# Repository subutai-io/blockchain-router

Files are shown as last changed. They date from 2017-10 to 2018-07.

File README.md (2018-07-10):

# Subutai™ Blockchain Router

The Subutai™ Blockchain Router is a broadband cloud router and IoT gateway device designed to integrate with the blockchain. It is an open hardware project with sources available in this repository. Contents of the repository include:

* **FPGA** folder for IP cores and other FPGA Verilog projects
* **PCB** folder for the Subutai™ Blockchain Router's board designs

For more information about this project, please visit: https://subutai.io/router.html

Sunshine,
OptDyn Hardware Team

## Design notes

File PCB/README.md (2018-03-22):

# The PCB folder include Subutai™ Blockchain Router's design

The SRv2.0 folder include Subutai™ Blockchain Router's v2.0 design

For more information about this project, please visit: https://subutai.io/router.html

Sunshine,

OptDyn Hardware Team

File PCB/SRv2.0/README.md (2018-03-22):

# Subutai™ Blockchain Router
The Subutai™ Blockchain Router open hardware project sources.

The 3DRender includes the 3D pdf of the board.

Assembly folder includes the assembly drawing of the components on the board layout.

The BOM folder includes the BOM list of the PCB.

The DesignRuleCheck folder includes the Design Rule Check Results made.

The Manufacturing folder includes the Gerber, Drill, ODB++, Manufacturing pdf and Pick n Place documents.

The Project includes the schematic and Pcb files.

The SchematicPdf folder includes the schematic in the form of pdf.

For more information about this project, please visit: https://subutai.io/router.html

Sunshine,

OptDyn Hardware Team

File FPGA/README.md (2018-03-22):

# The FPGA folder includes IP cores, FPGA projects for Subutai™ Blockchain Router
The Subutai™ Blockchain Router open hardware project sources.

For more information about this project, please visit: https://subutai.io/router.html

Sunshine,

OptDyn Hardware Team

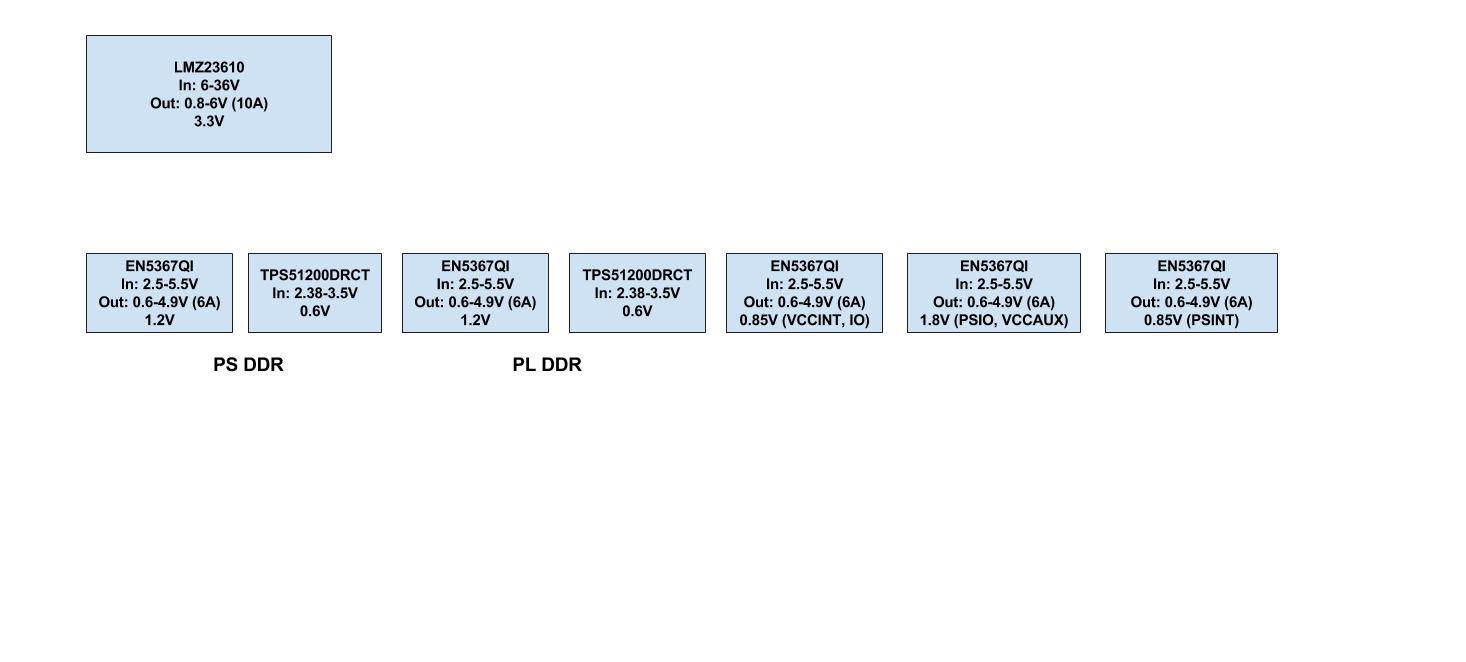
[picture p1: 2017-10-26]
PCB/SRv2.0/Documents/Power Regulators.jpg

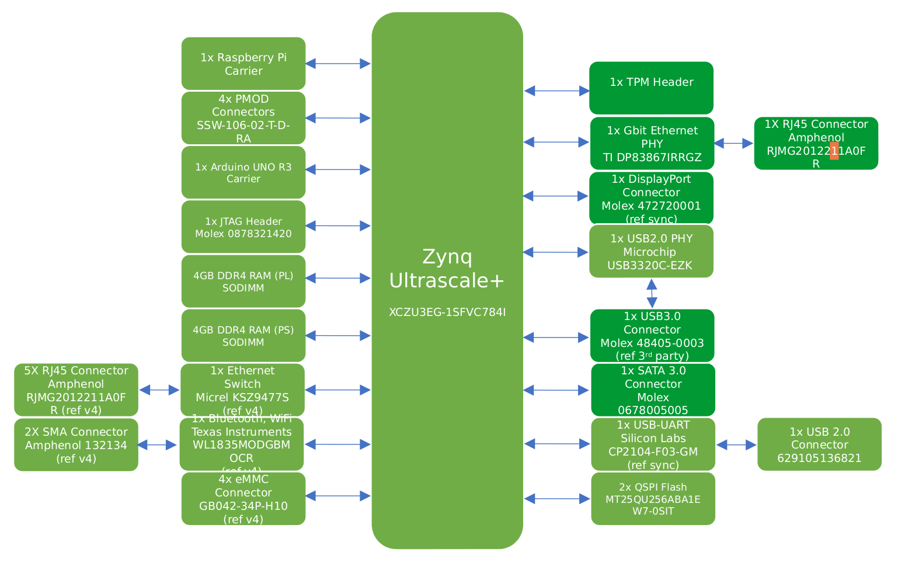
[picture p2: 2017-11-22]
PCB/SRv2.0/Documents/Screenshot from 2017-11-22 23-14-22.png

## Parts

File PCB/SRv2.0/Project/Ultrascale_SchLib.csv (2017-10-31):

LIBRARYREFERENCE | FOOTPRINT1 | .CHECKED PCB | .CHECKED SCH | .CREATOR | 3D PACKAGE | 3-STATE OUTPUT | ALLIED_NUMBER | ANTENNA TYPE | APPLICATIONS | AUTHOR | BITS(#) | C | CAPACITANCE | CAPACITANCE TOLERANCE | CAPACITANCE TOLERANCE ± | CAPACITOR TERMINALS | CARD TYPE | CASE | CATEGORY | CERAMIC CAPACITOR CASE | CHANNEL TYPE | CHANNELS PER CIRCUIT | CODE_IPC | CODE_JEDEC | COLOR | COMMENT | COMPONENT KIND | COMPONENT TYPE | COMPONENTHEIGHT | COMPONENTLINK1DESCRIPTION | COMPONENTLINK1URL | COMPONENTLINK2DESCRIPTION | COMPONENTLINK2URL | COMPONENTLINK3DESCRIPTION | COMPONENTLINK3URL | COMPOSITION | CONNECTOR STYLE | CONNECTOR TYPE | CONTACT FINISH | CONTACT FINISH - MATING | CONTACT FINISH - POST | CONTACT FINISH THICKNESS | CONTACT FINISH THICKNESS - MATING | CONTACT FINISH THICKNESS - POST | CONTACT LENGTH - MATING | CONTACT LENGTH - POST | CONTACT MATERIAL | CONTACT SHAPE | CONTACT TYPE | COPYRIGHT | CREATEDATE | CURRENT - OUTPUT | CURRENT - OUTPUT HIGH, LOW | CURRENT - PEAK PULSE (10/1000µS) | CURRENT - QUIESCENT (MAX) | CURRENT - RECEIVING | CURRENT - SATURATION | CURRENT - SUPPLY (DISABLE) (MAX) | CURRENT - SUPPLY (MAX)
0878321420 | 0878321420 |  |  |  |  |  |  |  |  |  |  |  |  |  |  |  |  |  |  |  |  |  |  |  |  | 0878321420 |  |  |  | Drawing | C:\Users\Public\Documents\Altium\AD16\Library\PDF\878322620_sd.pdf
2309409-2 | DDR4_SODIMM_MATING |  |  |  |  |  |  |  |  |  |  |  |  |  |  |  |  |  |  |  |  |  |  |  |  | 2309409-2 |  |  |  | Datasheet | C:\Users\Public\Documents\Altium\AD16\Library\PDF\ENG_CD_2309409_3.pdf
ABM8G-25.000MHZ-18-D2Y-T | ABM8G |  |  |  |  |  |  |  |  |  |  |  |  |  |  |  |  |  |  |  |  |  |  |  |  | ABM8G-25.000MHZ-18-D2Y-T |  |  |  | Datasheet | C:\Users\Public\Documents\Altium\AD16\Library\PDF\ABM8G.pdf
ABS07AIG-32.768KHZ-1-T | ABS07 |  |  |  |  |  |  |  |  |  |  |  |  |  |  |  |  |  |  |  |  |  |  |  |  | ABS07AIG-32.768KHZ-1-T |  |  |  | Datasheet | C:\Users\Public\Documents\Altium\AD16\Library\PDF\ABS07.pdf
ADP223ACPZ-R7 | CP-8-10_LFCSP_UD |  |  |  |  |  |  |  |  |  |  |  |  |  |  |  |  |  |  |  |  |  |  |  |  | ADP223ACPZ-R7 |  |  |  | Datasheet | C:\Users\Public\Documents\Altium\AD16\Library\PDF\ADP222_223_224_225.pdf |  |  |  |  |  |  |  |  |  |  |  |  |  |  |  |  |  |  |  |  | 300mA
ASDMB-24.000MHZ-LY-T | ASDMB |  |  |  |  |  |  |  |  |  |  |  |  |  |  |  |  |  |  |  |  |  |  |  |  | ASDMB-24.000MHZ-LY-T |  |  |  | Datasheet | C:\Users\Public\Documents\Altium\AD16\Library\PDF\ASDMB.pdf
ASDMB-33.333MHZ-LY-T | ASDMB |  |  |  |  |  |  |  |  |  |  |  |  |  |  |  |  |  |  |  |  |  |  |  |  | ASDMB-33.333MHZ-LY-T |  |  |  | Datasheet | C:\Users\Public\Documents\Altium\AD16\Library\PDF\ASDMB.pdf
AT34C02D-MAHM | UDFN_9 |  |  |  |  |  |  |  |  |  |  |  |  |  |  |  |  |  |  |  |  |  | SOIC127P600-8 | MS-012-AA |  | AT34C02D-MAHM |  |  |  | Datasheet | C:\Users\Public\Documents\Altium\AD16\Library\PDF\Atmel-8781-SEEPROM-AT34C02D-Datasheet.pdf
BEAD0603_220_2A5_40M | INDC1608N_0603 |  |  |  |  |  |  |  |  |  |  |  |  |  |  |  |  |  |  |  |  |  |  |  |  |  |  |  |  | Datasheet | C:\Users\Public\Documents\Altium\AD16\Library\PDF\ENFA0003.pdf
BSS138-7-F | DIODES_SOT23 |  |  |  |  |  |  |  |  |  |  |  |  |  |  |  |  |  |  |  |  |  |  |  |  | BSS138-7-F |  |  |  | Datasheet | C:\Users\Public\Documents\Altium\AD16\Library\PDF\ds30144.pdf
C0603X5R1E104K030BB | CAP_0603 |  |  |  |  |  |  |  | General Purpose |  |  |  |  |  |  |  |  |  |  |  |  |  |  |  |  | *
C0805C105K5RACTU | C0805C105 |  |  |  | * |  | * |  | General Purpose |  |  |  |  |  |  |  |  |  |  |  |  |  |  |  |  | *
C0805C106K4PACTU | CAP 0805 |  |  |  | * |  | * |  | General Purpose |  |  |  |  |  |  |  |  |  |  |  |  |  |  |  |  | *
C3216X5R | CAPC3216X180N |  |  |  | * |  | * |  |  |  |  |  |  |  |  |  |  |  |  |  |  |  |  |  |  | C3216X5R1C476M160AB
CAP 04023C103KAT2A | CAPC1005X56N |  |  |  |  |  |  |  |  |  |  |  | 10000pF |  |  |  |  |  |  |  |  |  |  |  |  | 04023C103KAT2A
CAP 04023C104 | CAP 04023C104 |  |  |  | * |  | * |  |  |  |  |  |  |  |  |  |  |  |  |  |  |  |  |  |  | 04023C104KAT2A
CAP 0402ZD106 | CAP 0402ZD106 |  |  |  |  |  |  |  |  |  |  |  |  |  |  |  |  |  |  |  |  |  |  |  |  | 0402ZD106MAT2A
CAP 06035C104 | CAP 06035C104 |  |  |  |  |  | 70002065 |  |  |  |  |  |  |  |  |  |  |  |  |  |  |  |  |  |  | 06035C104KAT2A
CAP 08053D475KAT2A | CAPC2012X140N |  |  |  |  |  |  |  |  |  |  |  | 4.7µF |  |  |  |  |  |  |  |  |  |  |  |  | 08053D475KAT2A
CAP C1005X5R1A475K050BC | CAPC1005X5 |  |  |  |  |  |  |  |  |  |  |  | 4.7µF |  |  |  |  |  |  |  |  |  |  |  |  | C1005X5R1A475K050BC
CAP C1608X5R1A226M080AC | CAPC1608X80N |  |  |  |  |  |  |  |  |  |  |  | 22µF |  |  |  |  |  |  |  |  |  |  |  |  | C1608X5R1A226M080AC
CAP C2012X5R1E226M125AC | CAPC2012X145N |  |  |  |  |  |  |  |  |  |  |  | 22µF |  |  |  |  |  |  |  |  |  |  |  |  | C2012X5R1E226M125AC
CAP C3216X5R1C476M160AB | CAPC3216X180N |  |  |  |  |  |  |  |  |  |  |  | 47µF |  |  |  |  |  |  |  |  |  |  |  |  | C3216X5R1C476M160AB
CAP GRM155R61E105KA12D | CAPC1005X55N |  |  |  |  |  |  |  |  |  |  |  | 1µF |  |  |  |  |  |  |  |  |  |  |  |  | GRM155R61E105KA12D
CAP GRM188R61E225KA12D | CAPC1608X90N |  |  |  |  |  |  |  |  |  |  |  | 2.2µF |  |  |  |  |  |  |  |  |  |  |  |  | GRM188R61E225KA12D
CAP GRM31CR61E226 | CAP GRM31CR61E226 |  |  |  |  |  |  |  | General Purpose |  |  |  |  |  |  |  |  |  |  |  |  |  |  |  |  | GRM31CR61E226KE15L
CAPCER0402 | CAPC1005L_0402 |  |  |  |  |  |  |  |  |  |  |  |  |  |  |  |  |  |  |  |  |  |  |  |  | =Value |  |  |  | Datasheet
CAPCER0402C0G27P50V_5T | CAPC1005L_0402 |  |  |  |  |  |  |  |  |  |  |  |  |  |  |  |  |  |  |  |  |  |  |  |  | =Value |  |  |  | Datasheet
CAPCER0402C0G68P50V_5T | CAPC1005L_0402 |  |  |  |  |  |  |  |  |  |  |  |  |  |  |  |  |  |  |  |  |  |  |  |  | =Value |  |  |  | Datasheet
CAPCER0402X5R0U4710V_10T | CAPC1005L_0402 |  |  |  |  |  |  |  |  |  |  |  |  |  |  |  |  |  |  |  |  |  |  |  |  | =Value |  |  |  | Datasheet
CAPCER0402X5R10U10V_20T | CAPC1005L_0402 |  |  |  |  |  |  |  |  |  |  |  |  |  |  |  |  |  |  |  |  |  |  |  |  | =Value |  |  |  | Datasheet
CAPCER0402X5R1U16V_20T | CAPC1005L_0402 |  |  |  |  |  |  |  |  |  |  |  |  |  |  |  |  |  |  |  |  |  |  |  |  | =Value |  |  |  | Datasheet
CAPCER0402X5R2U210V_10T | CAPC1005L_0402 |  |  |  |  |  |  |  |  |  |  |  |  |  |  |  |  |  |  |  |  |  |  |  |  | =Value |  |  |  | Datasheet
CAPCER0402X5R4U710V_10T | CAPC1005L_0402 |  |  |  |  |  |  |  |  |  |  |  |  |  |  |  |  |  |  |  |  |  |  |  |  | =Value |  |  |  | Datasheet
CAPCER0402X7R1000P50V_10T | CAPC1005L_0402 |  |  |  |  |  |  |  |  |  |  |  |  |  |  |  |  |  |  |  |  |  |  |  |  | =Value |  |  |  | Datasheet
CAPCER0402X7R100N25V_10T | CAPC1005L_0402 |  |  |  |  |  |  |  |  |  |  |  |  |  |  |  |  |  |  |  |  |  |  |  |  | =Value |  |  |  | Datasheet
CAPCER0402X7R10N50V_10T | CAPC1005L_0402 |  |  |  |  |  |  |  |  |  |  |  |  |  |  |  |  |  |  |  |  |  |  |  |  | =Value |  |  |  | Datasheet
CAPCER0402X7R22N50V_10T | CAPC1005L_0402 |  |  |  |  |  |  |  |  |  |  |  |  |  |  |  |  |  |  |  |  |  |  |  |  | =Value |  |  |  | Datasheet
CAPCER0402X7R2700P50V_10T | CAPC1005L_0402 |  |  |  |  |  |  |  |  |  |  |  |  |  |  |  |  |  |  |  |  |  |  |  |  | =Value |  |  |  | Datasheet
CAPCER0603X5R22U10V_20T | CAPC1608L_0603 |  |  |  |  |  |  |  |  |  |  |  |  |  |  |  |  |  |  |  |  |  |  |  |  | =Value |  |  |  | Datasheet
CAPCER0805X5R22U25V_20T | CAPC2012L_0805 |  |  |  |  |  |  |  |  |  |  |  |  |  |  |  |  |  |  |  |  |  |  |  |  | =Value |  |  |  | Datasheet
CAPCER1206X5R47U25V_20T | CAPC3216L_1206 |  |  |  |  |  |  |  |  |  |  |  |  |  |  |  |  |  |  |  |  |  |  |  |  | =Value |  |  |  | Datasheet
CAPCER1210X5R100U16V_20T | CAPC3225N_1210 |  |  |  |  |  |  |  |  |  |  |  |  |  |  |  |  |  |  |  |  |  |  |  |  | =Value |  |  |  | Datasheet
CAPCER1210X5R220U6V3_20T | CAPC3225N_1210 |  |  |  |  |  |  |  |  |  |  |  |  |  |  |  |  |  |  |  |  |  |  |  |  | =Value |  |  |  | Datasheet
CAPELE0603TAN47U6V3_20T | AVX_TAN_F38_M_0603 |  |  |  |  |  |  |  |  |  |  |  |  |  |  |  |  |  |  |  |  |  |  |  |  | =Value |  |  |  | Datasheet | C:\Users\Public\Documents\Altium\AD16\Library\PDF\f38.pdf
CAPELE0905TAN100U6V3_20T | AVX_TAN_F95_P_0905 |  |  |  |  |  |  |  |  |  |  |  |  |  |  |  |  |  |  |  |  |  |  |  |  | =Value |  |  |  | Datasheet | C:\Users\Public\Documents\Altium\AD16\Library\PDF\F95.pdf
CON RJ-45 RJMG2012211A0FR | CON_MODULAR_RJ45_TH_RA_RJMG2012211A0FR |  |  |  |  |  |  |  |  |  |  |  |  |  |  |  |  |  |  |  |  |  |  |  |  | =Value |  |  |  | Datasheet | https://www.amphenolcanada.com/ProductSearch/Drawings/AC/RJMG2012211A0FR.PDF
CONN 39-30-1060 | 39-30-1060 |  |  |  |  |  |  |  |  |  |  |  |  |  |  |  |  |  |  |  |  |  |  |  |  | 39-30-1060 |  |  |  |  |  |  |  |  |  |  |  | Header |  | Tin | Tin |  | 100µin (2.54µm) | 100µin (2.54µm) |  | 0.142 (3.60mm)" | Brass | Square | Male Pin
CONN 878321420 | 87832-1420 |  |  |  |  |  |  |  |  |  |  |  |  |  |  |  |  |  |  |  |  |  |  |  |  | CONN 878321420 |  |  |  |  |  |  |  |  |  |  |  | Header |  | Gold | Tin |  | 74.8µin (1.90µm) |  | 0.141 (3.60mm)" |  | Phosphor Bronze | Square | Male Pin
CP2104-F03-GM | SLAB-QFN-24-2675x2675TP_L |  |  |  |  |  |  |  |  |  |  |  |  |  |  |  |  |  |  |  |  |  | J-STD-020 | MO-220 |  | CP2104-F03-GM |  |  |  | Manufacturer URL | http://www.silabs.com/ | Datasheet | C:\Users\Public\Documents\Altium\AD16\Library\PDF\cp2104.pdf | Package Specification | http://www.silabs.com/Support%20Documents/TechnicalDocs/C8051F93x-92x.pdf
CRCW020111K0FKED | RES_V0201 |  |  |  |  |  |  |  |  |  |  | Copyright (C) 2015 Accelerated Designs. All rights reserved |  |  |  |  |  |  |  |  |  |  |  |  |  | * |  |  |  |  |  |  |  |  |  |  |  |  |  |  |  |  |  |  |  |  |  |  |  | Copyright (C) 2015 Accelerated Designs. All rights reserved
CRCW0201240RFNED | RESC0603X28N |  |  |  | * |  | * |  |  |  |  |  |  |  |  |  |  |  |  |  |  |  |  |  |  | CRCW0201240RFNED
CRCW02012K49FKED | RC0201N |  |  |  |  |  |  |  |  |  |  | Copyright (C) 2015 Accelerated Designs. All rights reserved |  |  |  |  |  | 0201 (0603 metric) |  |  |  |  |  |  |  | * |  |  |  |  |  |  |  |  |  | Thick Film |  |  |  |  |  |  |  |  |  |  |  |  |  | Copyright (C) 2015 Accelerated Designs. All rights reserved
Capacitor - non polarized | CAPC1608X87N |  |  |  |  |  |  |  |  | CERN DEM JLC |  |  | 0.1 | ± 10% | ± 10% | SMD |  | 0603 |  | 0603 [1608 Metric] |  |  |  |  |  | =Value | Standard | Standard |  |  |  |  |  |  |  |  |  |  |  |  |  |  |  |  |  |  |  |  |  |  | 3.12.2007
Capacitor NP | CAP_C_0402 |  |  |  |  |  |  |  |  |  |  |  |  |  |  |  |  |  | Capacitor |  |  |  |  |  |  | Capacitor NP |  |  |  | Datasheets | https://chn-vm-apps.microchip.com/mchprepo/parts/Datasheets/TDKMLCCCapRange.pdf
Coax_1Female_1Shield | HUBER-SUHNER_82 SMA-50-0-41/133 NE |  |  |  |  |  |  |  |  | CERN DEM JLC |  |  |  |  |  |  |  |  |  |  |  |  |  |  |  | Coax_1Female_1Shield | Standard | Standard | 9.6mm |  |  |  |  |  |  |  |  |  |  |  |  |  |  |  |  |  |  |  |  |  | 20.04.2010
D CDSOT23-SR208 | SOT95P280X130-6N |  |  |  |  |  |  |  |  |  |  |  |  |  |  |  |  |  |  |  |  |  |  |  |  | CDSOT23-SR208
D MBRS240LT3G | DIOM5436X247N |  |  |  | * |  | 70099506 |  |  |  |  |  |  |  |  |  |  |  |  |  |  |  |  |  |  | MBRS240LT3G
D TPD2EUSB30DRTR | SOTFL35P100X50-3N |  |  |  |  |  |  |  |  |  |  |  |  |  |  |  |  |  |  |  |  |  |  |  |  | TPD2EUSB30DRTR |  |  |  |  |  |  |  |  |  |  |  |  |  |  |  |  |  |  |  |  |  |  |  |  |  |  |  | 1A (8/20µs)
D TPD4E001DRLR | SOTFL50P160X60-6N |  |  |  |  |  |  |  | Ethernet |  |  |  |  |  |  |  |  |  |  |  |  |  |  |  |  | TPD4E001DRLR
DP83867IRRGZ | QFN50P700X700X100_HS-49N |  |  |  |  |  |  |  |  |  |  |  |  |  |  |  |  |  |  |  |  |  |  |  |  | DP83867IRRGZ |  |  |  | Datasheet | C:\Users\Public\Documents\Altium\AD16\Library\PDF\dp83867ir.pdf
DSC1101B12-125.0000 | OSC_5MX3M2_A |  |  |  |  |  |  |  |  |  |  |  |  |  |  |  |  |  | Crystals and Oscillators |  |  |  |  |  |  | =value |  |  |  | Datasheet | http://www.ctscorp.com/components/Datasheets/008-0256-0.pdf
DisplayPort | 8470-2-2-X |  |  |  |  |  |  |  |  |  |  |  |  |  |  |  |  |  |  |  |  |  |  |  |  | * |  |  |  |  |  |  |  |  |  |  |  | DisplayPort | Gold
ERJ-1GEF2211C | RC0201N |  |  |  |  |  |  |  |  |  |  | Copyright (C) 2015 Accelerated Designs. All rights reserved |  |  |  |  |  | 0201 (0603 metric) |  |  |  |  |  |  |  | * |  |  |  |  |  |  |  |  |  | Thick Film |  |  |  |  |  |  |  |  |  |  |  |  |  | Copyright (C) 2015 Accelerated Designs. All rights reserved
ERJ-1GEF5761C | RC0201N |  |  |  |  |  |  |  |  |  |  | Copyright (C) 2015 Accelerated Designs. All rights reserved |  |  |  |  |  | 0201 (0603 metric) |  |  |  |  |  |  |  | * |  |  |  |  |  |  |  |  |  | Thick Film |  |  |  |  |  |  |  |  |  |  |  |  |  | Copyright (C) 2015 Accelerated Designs. All rights reserved
ERJ-1GEF8061C | RC0201N |  |  |  |  |  |  |  |  |  |  | Copyright (C) 2015 Accelerated Designs. All rights reserved |  |  |  |  |  | 0201 (0603 metric) |  |  |  |  |  |  |  | * |  |  |  |  |  |  |  |  |  | Thick Film |  |  |  |  |  |  |  |  |  |  |  |  |  | Copyright (C) 2015 Accelerated Designs. All rights reserved
F BLM15AG601SN1D | BEADC1005X55N |  |  |  |  |  |  |  |  |  |  |  |  |  |  |  |  |  |  |  |  |  |  |  |  | BLM15AG601SN1D
FIN1019MTCX | TSOP65P640X120-14N |  |  |  |  |  |  |  |  |  |  |  |  |  |  |  |  |  |  |  |  |  |  |  |  | *
Ferrite Bead | IND_C_0805 |  |  |  |  |  |  |  |  |  |  |  |  |  |  |  |  |  | Inductor |  |  |  |  |  |  | Ferrite Bead |  |  |  | Datasheet | https://chn-vm-apps.microchip.com/mchprepo/parts/Datasheets/beads_commercial_power_mpz_en
GB042-34P-H10 | GB042-34P-H10 |  |  |  |  |  |  |  |  |  |  |  |  |  |  |  |  |  |  |  |  |  |  |  |  | GB042-34P-H10
GRM033R61A225KE47D | CAPC0603X33N |  |  |  |  |  |  |  |  |  |  |  |  |  |  |  |  |  |  |  |  |  |  |  |  | GRM033R61A225KE47D
Header 1x2 | HDR_M_2.54_1x2 |  |  |  |  |  |  |  |  |  |  |  |  |  |  |  |  |  |  |  |  |  |  |  |  | =value
IND3030_2U2_1A8_72M | IND_SRN3015 |  |  |  |  |  |  |  |  |  |  |  |  |  |  |  |  |  |  |  |  |  |  |  |  |  |  |  |  | Datasheet | C:\Users\Public\Documents\Altium\AD16\Library\PDF\SRN3015.pdf |  |  |  |  |  |  |  |  |  |  |  |  |  |  |  |  |  |  |  |  |  |  |  |  |  | 1.65A
IND5752_3U3_5A_38M | IND_SRP5030T |  |  |  |  |  |  |  |  |  |  |  |  |  |  |  |  |  |  |  |  |  |  |  |  |  |  |  |  | Datasheet | C:\Users\Public\Documents\Altium\AD16\Library\PDF\SRP5030T.pdf |  |  |  |  |  |  |  |  |  |  |  |  |  |  |  |  |  |  |  |  |  |  |  |  |  | 8A
INDC2520_1U5_2A9_66M | INDC2520 |  |  |  |  |  |  |  |  |  |  |  |  |  |  |  |  |  |  |  |  |  |  |  |  |  |  |  |  | Datasheet | C:\Users\Public\Documents\Altium\AD16\Library\PDF\ihhp-1008ab-01.pdf |  |  |  |  |  |  |  |  |  |  |  |  |  |  |  |  |  |  |  |  |  |  |  |  |  | 3.4A
IRPS5401MTRPBF | QFN40P700X700X90_HS-57N |  |  |  |  |  |  |  |  |  |  |  |  |  |  |  |  |  |  |  |  |  |  |  |  | IRPS5401MTRPBF |  |  |  | Datasheet | C:\Users\Public\Documents\Altium\AD16\Library\PDF\Infineon-PB-IRPS5401-PB-v01_00-EN.pdf
Inductor | IND_TAI_NR_L3W3H1.5 |  |  |  |  |  |  |  |  |  |  |  |  |  |  |  |  |  | Inductor |  |  |  |  |  |  | Inductor |  |  |  | Datasheet | https://chn-vm-apps.microchip.com/mchprepo/parts/Datasheets/NR3015T1R0N.pdf
KSZ9477S_TQFP128 | TQFP-128_14x14_EP10x10 |  |  |  |  |  |  |  |  |  |  |  |  |  |  |  |  |  |  |  |  |  |  |  |  | =Value
LED0603BLUE | LED0603BLUE |  |  |  |  |  |  |  |  |  |  |  |  |  |  |  |  |  |  |  |  |  |  |  |  |  |  |  |  | Datasheet | C:\Users\Public\Documents\Altium\AD16\Library\PDF\AV02-0592EN0.pdf
LED0603GREEN | LED0603GREEN |  |  |  |  |  |  |  |  |  |  |  |  |  |  |  |  |  |  |  |  |  |  |  |  |  |  |  |  | Datasheet | C:\Users\Public\Documents\Altium\AD16\Library\PDF\AV02-0592EN0.pdf
LED0603RED | LED0603RED |  |  |  |  |  |  |  |  |  |  |  |  |  |  |  |  |  |  |  |  |  |  |  |  |  |  |  |  | Datasheet | C:\Users\Public\Documents\Altium\AD16\Library\PDF\AV02-0592EN0.pdf
M20-7820646 | Hdr_Female_1x6_2.54mm | MM | MM | MM |  |  |  |  |  |  |  |  |  |  |  |  |  |  | Connectors, Interconnects |  |  |  |  |  | Black | HDR FMALE 1x6 2.54mm |  |  |  | http://harwin.com/includes/pdfs/M20-782.pdf | http://harwin.com/includes/pdfs/M20-782.pdf |  |  |  |  |  |  | Receptacle | Tin |  |  | - |  |  |  |  |  |  | Female Socket
M20-7820842 | Hdr_Female_1x8_2.54mm | RF | RF | MM |  |  |  |  |  |  |  |  |  |  |  |  |  |  | Connectors, Interconnects |  |  |  |  |  | Black | HDR FMALE 1x8 2.54mm |  |  |  | http://harwin.com/includes/pdfs/M20-782.pdf | http://harwin.com/includes/pdfs/M20-782.pdf |  |  |  |  |  |  | Receptacle | Gold |  |  | Flash |  |  |  |  |  |  | Female Socket
M20-7821046 | Hdr_Female_1x10_2.54mm | RF | RF | MM |  |  |  |  |  |  |  |  |  |  |  |  |  |  | Connectors, Interconnects |  |  |  |  |  | Black | HDR FMALE 1x10 2.54mm |  |  |  | http://harwin.com/includes/pdfs/M20-782.pdf | http://harwin.com/includes/pdfs/M20-782.pdf |  |  |  |  |  |  | Receptacle | Tin |  |  | - |  |  |  |  |  |  | Female Socket
MAX15027 | MAX15027_T1033+1_V |  |  |  |  |  |  |  |  |  |  |  |  |  |  |  |  |  |  |  |  |  |  |  |  | MAX15027 |  |  |  | Datasheet | C:\Users\Public\Documents\Altium\AD16\Library\PDF\MAX15027-MAX15028.pdf
MAX16025TE+ | T1644+4_L |  |  |  |  |  |  |  |  |  |  |  |  |  |  |  |  |  |  |  |  |  |  |  |  | MAX16025TE+ |  |  |  | Datasheet | C:\Users\Public\Documents\Altium\AD16\Library\PDF\MAX16025-MAX16030.pdf
MAX8902BATA+T | 21-0168E_T822-1 |  |  |  |  |  |  |  |  |  |  | Copyright (C) 2015 Accelerated Designs. All rights reserved |  |  |  |  |  |  |  |  |  |  |  |  |  | * |  |  |  |  |  |  |  |  |  |  |  |  |  |  |  |  |  |  |  |  |  |  |  | Copyright (C) 2015 Accelerated Designs. All rights reserved
MIC23303YML | DFN-12_3x3 |  |  |  |  |  |  |  |  |  |  |  |  |  |  |  |  |  |  |  |  |  |  |  |  | =Value
MT25QU256ABA1EW7-0SIT | W-PDFN-8_6x5mm |  |  |  |  |  |  |  |  |  |  |  |  |  |  |  |  |  |  |  |  |  |  |  |  | MT25QU256ABA1EW7-0SIT |  |  |  | Datasheet | C:\Users\Public\Documents\Altium\AD16\Library\PDF\MT25Q_QLJS_U_256_ABA_0.pdf
MT40A512M16JY-083E IT:B | BGA96C80P9X16_800X1400X120 |  |  |  |  |  |  |  |  |  |  |  |  |  |  |  |  |  |  |  |  |  |  |  |  | MT40A512M16JY-083E IT:B |  |  |  | Datasheet | C:\Users\Public\Documents\Altium\AD16\Library\PDF\8Gb_DDR4_SDRAM.pdf
MTFC8GAKAJCN-4M IT | eMMC |  |  |  |  |  |  |  |  |  |  |  |  |  |  |  |  |  |  |  |  |  |  |  |  | MTFC8GAKAJCN-4M IT |  |  |  | Datasheet | C:\Users\Public\Documents\Altium\AD16\Library\PDF\
Oscillator 1E 2GND 3OUT 4Vs | OSCSC508P500X700X180-4N |  |  |  |  |  |  |  |  | CERN DEM JLC |  |  |  |  |  |  |  |  | Crystals and Oscillators |  |  |  |  |  |  | =Value | Standard | Standard | 2mm |  |  |  |  |  |  |  |  |  |  |  |  |  |  |  |  |  |  |  |  |  | 5.10.2009 |  |  |  |  |  |  | - | 2µA
PMOD SSW-106-02-G-D-RA | SSW-106-02-G-D-RA |  |  |  |  |  |  |  |  |  |  |  |  |  |  |  |  |  |  |  |  |  |  |  |  | SSW-106-02-G-D-RA |  |  |  |  |  |  |  |  |  |  |  | Receptacle |  | Tin | Tin |  |  |  |  | 0.100 (2.54mm)" | Phosphor Bronze | Square | Forked
R CRCW04024K70FKED | RESC1005X40N |  |  |  |  |  |  |  |  |  |  |  |  |  |  |  |  |  |  |  |  |  |  |  |  | CRCW04024K70FKED |  |  |  |  |  |  |  |  |  | Thick Film
REF3012AIDBZT | TI-DBZ3_N |  |  |  |  |  |  |  |  |  |  |  |  |  |  |  |  |  |  |  |  |  |  |  |  | REF3012AIDBZT |  |  |  | Datasheet | C:\Users\Public\Documents\Altium\AD16\Library\PDF\ref3012.pdf
RES0402 | RESC1005L_0402 |  |  |  |  |  |  |  |  |  |  |  |  |  |  |  |  |  |  |  |  |  |  |  |  | RES0402 |  |  |  | Datasheet
RES0402_0R_0W1 | RESC1005L_0402 |  |  |  |  |  |  |  |  |  |  |  |  |  |  |  |  |  |  |  |  |  |  |  |  | RES0402_0R_0W1 |  |  |  | Datasheet
RES0402_100K_0W2_1T | RESC1005L_0402 |  |  |  |  |  |  |  |  |  |  |  |  |  |  |  |  |  |  |  |  |  |  |  |  | RES0402_100K_0W2_1T |  |  |  | Datasheet
RES0402_100R_0W1_1T | RESC1005L_0402 |  |  |  |  |  |  |  |  |  |  |  |  |  |  |  |  |  |  |  |  |  |  |  |  | RES0402_100R_0W1_1T |  |  |  | Datasheet
RES0402_10K_0W1_05T | RESC1005L_0402 |  |  |  |  |  |  |  |  |  |  |  |  |  |  |  |  |  |  |  |  |  |  |  |  | RES0402_10K_0W1_05T |  |  |  | Datasheet
RES0402_11K_0W1_1T | RESC1005L_0402 |  |  |  |  |  |  |  |  |  |  |  |  |  |  |  |  |  |  |  |  |  |  |  |  | RES0402_11K_0W1_1T |  |  |  | Datasheet
RES0402_18K2 | RES_CRCW_0402 |  |  |  |  |  |  |  |  |  |  | Copyright (C) 2015 Accelerated Designs. All rights reserved |  |  |  |  |  |  |  |  |  |  |  |  |  | * |  |  |  |  |  |  |  |  |  |  |  |  |  |  |  |  |  |  |  |  |  |  |  | Copyright (C) 2015 Accelerated Designs. All rights reserved
RES0402_1K3_0W1_1T | RESC1005L_0402 |  |  |  |  |  |  |  |  |  |  |  |  |  |  |  |  |  |  |  |  |  |  |  |  | RES0402_1K3_0W1_1T |  |  |  | Datasheet
RES0402_1K5 | RESC1005L_0402 |  |  |  |  |  |  |  |  |  |  |  |  |  |  |  |  |  |  |  |  |  |  |  |  |  |  |  |  | Datasheet
RES0402_1K_0W1_1T | RESC1005L_0402 |  |  |  |  |  |  |  |  |  |  |  |  |  |  |  |  |  |  |  |  |  |  |  |  | RES0402_1K_0W1_1T |  |  |  | Datasheet
RES0402_1M | RESC1005L_0402 |  |  |  |  |  |  |  |  |  |  |  |  |  |  |  |  |  |  |  |  |  |  |  |  |  |  |  |  | Datasheet
RES0402_20K5_0W1_1T | RESC1005L_0402 |  |  |  |  |  |  |  |  |  |  |  |  |  |  |  |  |  |  |  |  |  |  |  |  | RES0402_20K5_0W1_1T |  |  |  | Datasheet
RES0402_22R_0W1_1T | RESC1005L_0402 |  |  |  |  |  |  |  |  |  |  |  |  |  |  |  |  |  |  |  |  |  |  |  |  | RES0402_22R_0W1_1T |  |  |  | Datasheet
RES0402_240R_0W1_1T | RESC1005L_0402 |  |  |  |  |  |  |  |  |  |  |  |  |  |  |  |  |  |  |  |  |  |  |  |  | RES0402_240R_0W1_1T |  |  |  | Datasheet
RES0402_24K_0W1 | RESC1005L_0402 |  |  |  |  |  |  |  |  |  |  |  |  |  |  |  |  |  |  |  |  |  |  |  |  | RES0402_24K_0W1 |  |  |  | Datasheet
RES0402_2K21_0W1_1T | RESC1005L_0402 |  |  |  |  |  |  |  |  |  |  |  |  |  |  |  |  |  |  |  |  |  |  |  |  | RES0402_2K21_0W1_1T |  |  |  | Datasheet
RES0402_2K49_0W1_1T | RESC1005L_0402 |  |  |  |  |  |  |  |  |  |  |  |  |  |  |  |  |  |  |  |  |  |  |  |  | RES0402_2K49_0W1_1T |  |  |  | Datasheet
RES0402_2K_0W1_1T | RESC1005L_0402 |  |  |  |  |  |  |  |  |  |  |  |  |  |  |  |  |  |  |  |  |  |  |  |  | RES0402_2K_0W1_1T |  |  |  | Datasheet
RES0402_2R_0W1_1T | RESC1005L_0402 |  |  |  |  |  |  |  |  |  |  |  |  |  |  |  |  |  |  |  |  |  |  |  |  | RES0402_2R_0W1_1T |  |  |  | Datasheet
RES0402_36R5_0W1_1T | RESC1005L_0402 |  |  |  |  |  |  |  |  |  |  |  |  |  |  |  |  |  |  |  |  |  |  |  |  | RES0402_36R5_0W1_1T |  |  |  | Datasheet
RES0402_40K2_0W1_1T | RESC1005L_0402 |  |  |  |  |  |  |  |  |  |  |  |  |  |  |  |  |  |  |  |  |  |  |  |  | RES0402_40K2_0W1_1T |  |  |  | Datasheet
RES0402_40R2_0W1_1T | RESC1005L_0402 |  |  |  |  |  |  |  |  |  |  |  |  |  |  |  |  |  |  |  |  |  |  |  |  | RES0402_40R2_0W1_1T |  |  |  | Datasheet
RES0402_47K_0W1 | RESC1005L_0402 |  |  |  |  |  |  |  |  |  |  |  |  |  |  |  |  |  |  |  |  |  |  |  |  | RES0402_47K_0W1 |  |  |  | Datasheet
RES0402_49.9 | RESC1005L_0402 |  |  |  |  |  |  |  |  |  |  |  |  |  |  |  |  |  |  |  |  |  |  |  |  |  |  |  |  | Datasheet
RES0402_499R_0W1_1T | RESC1005L_0402 |  |  |  |  |  |  |  |  |  |  |  |  |  |  |  |  |  |  |  |  |  |  |  |  | RES0402_499R_0W1_1T |  |  |  | Datasheet
RES0402_4K02 | RC0402N |  |  |  |  |  |  |  |  |  |  | Copyright (C) 2015 Accelerated Designs. All rights reserved |  |  |  |  |  | 0402 (1005 metric) |  |  |  |  |  |  |  | * |  |  |  |  |  |  |  |  |  | Thick Film |  |  |  |  |  |  |  |  |  |  |  |  |  | Copyright (C) 2015 Accelerated Designs. All rights reserved
RES0402_4K64_0W1_1T | RESC1005L_0402 |  |  |  |  |  |  |  |  |  |  |  |  |  |  |  |  |  |  |  |  |  |  |  |  | RES0402_4K64_0W1_1T |  |  |  | Datasheet
RES0402_4K7_0W1_1T | RESC1005L_0402 |  |  |  |  |  |  |  |  |  |  |  |  |  |  |  |  |  |  |  |  |  |  |  |  | RES0402_4K7_0W1_1T |  |  |  | Datasheet
RES0402_4M7_0W1_5T | RESC1005L_0402 |  |  |  |  |  |  |  |  |  |  |  |  |  |  |  |  |  |  |  |  |  |  |  |  | RES0402_4M7_0W1_5T |  |  |  | Datasheet
RES0402_500R_0W05_01T | RESC1005L_0402 |  |  |  |  |  |  |  |  |  |  |  |  |  |  |  |  |  |  |  |  |  |  |  |  | RES0402_500R_0W05_01T |  |  |  | Datasheet
RES0402_5K76_0W1_1T | RESC1005L_0402 |  |  |  |  |  |  |  |  |  |  |  |  |  |  |  |  |  |  |  |  |  |  |  |  | RES0402_5K76_0W1_1T |  |  |  | Datasheet
RES0402_649R_0W1_1T | RESC1005L_0402 |  |  |  |  |  |  |  |  |  |  |  |  |  |  |  |  |  |  |  |  |  |  |  |  | RES0402_649R_0W1_1T |  |  |  | Datasheet
RES0402_6K49_0W1_1T | RESC1005L_0402 |  |  |  |  |  |  |  |  |  |  |  |  |  |  |  |  |  |  |  |  |  |  |  |  | RES0402_6K49_0W1_1T |  |  |  | Datasheet
RES0402_845R_0W1_1T | RESC1005L_0402 |  |  |  |  |  |  |  |  |  |  |  |  |  |  |  |  |  |  |  |  |  |  |  |  | RES0402_845R_0W1_1T |  |  |  | Datasheet
RES0402_8K06_0W1_1T | RESC1005L_0402 |  |  |  |  |  |  |  |  |  |  |  |  |  |  |  |  |  |  |  |  |  |  |  |  | RES0402_8K06_0W1_1T |  |  |  | Datasheet
Resistor | RES_C_0603 |  |  |  |  |  |  |  |  |  |  |  |  |  |  |  |  |  | Resistor |  |  |  |  |  |  | Resistor |  |  |  | Datasheet | https://chn-vm-apps.microchip.com/mchprepo/parts/Datasheets/AOA0000CE1.pdf |  |  |  |  | TKF
Resistor - 0.1% | RESC1608X55N |  |  |  |  |  |  |  |  | CERN DEM JLC |  |  |  |  |  |  |  | 0603 | Resistors |  |  |  |  |  |  | =Value | Standard | Standard |  |  |  |  |  |  |  | Thick Film |  |  |  |  |  |  |  |  |  |  |  |  |  |  | 3.12.2007
Resistor - 1% | RESC1608X55N |  |  |  |  |  |  |  |  | CERN DEM JLC |  |  |  |  |  |  |  | 0603 | Resistors |  |  |  |  |  |  | =Value | Standard | Standard |  |  |  |  |  |  |  | Thick Film |  |  |  |  |  |  |  |  |  |  |  |  |  |  | 3.12.2007
SATA 0678005005 | SATA HEADER |  |  |  |  |  |  |  |  |  |  |  |  |  |  |  |  |  |  |  |  |  |  |  |  | * |  |  |  |  |  |  |  |  |  |  | Header, Shrouded | SATA | Gold |  |  | 15µin (0.38µm)
SD 502570-0893 | 502570-0893_1 |  |  |  |  |  |  |  |  |  |  |  |  |  |  |  | Secure Digital - microSD™ |  |  |  |  |  |  |  |  | 502570-0893 |  |  |  |  |  |  |  |  |  |  |  | Connector and Ejector | Gold |  |  | 20µin (0.51µm)
SN74AVC1T45DCKR | DCK0006A_N |  |  |  |  | Yes |  |  |  |  | 1 |  |  |  |  |  |  |  |  |  |  |  |  |  |  | SN74AVC1T45DCKR |  |  |  | Manufacturer URL | C:\Users\Public\Documents\Altium\AD16\Library\PDF\sn74avc1t45.pdf
SN74LVC1G08DBVR | DBV0005A_N |  |  |  |  | No |  |  |  |  | 1 |  |  |  |  |  |  |  |  |  |  |  |  |  |  | SN74LVC1G08DBVR |  |  |  | Manufacturer URL | C:\Users\Public\Documents\Altium\AD16\Library\PDF\sn74lvc1g08.pdf
SN74LVC1G132DBVR | DBV0005A_N |  |  |  |  | No |  |  |  |  | 1 |  |  |  |  |  |  |  |  |  |  |  |  |  |  | SN74LVC1G132DBVR |  |  |  | Datasheet | C:\Users\Public\Documents\Altium\AD16\Library\PDF\sn74lvc1g132.pdf
SN74LVC1G132DBVT | SN74LVC1G132DBVT |  |  |  |  |  |  |  |  |  |  |  |  |  |  |  |  |  |  |  |  |  |  |  |  | * |  |  |  |  |  |  |  |  |  |  |  |  |  |  |  |  |  |  |  |  |  |  |  |  |  |  | 32mA, 32mA |  | 10µA
SP0503BAHTG | SP0503BAHT_SOT143 |  |  |  |  |  |  |  |  |  |  |  |  |  |  |  |  |  |  |  |  |  |  |  |  | SP0503BAHTG |  |  |  | Datasheet | C:\Users\Public\Documents\Altium\AD16\Library\PDF\SP05xxBA.pdf
SSW-106-02-T-D-RA | HDR2X6H |  |  |  |  |  |  |  |  |  |  |  |  |  |  |  |  |  |  |  |  |  |  |  |  | SSW-106-02-T-D-RA |  |  |  | Datasheet | C:\Users\Public\Documents\Altium\AD16\Library\PDF\ssw-1xx-xx-xxx-x-xx-xxx-xx-mkt.pdf
Switch DIP 8 Pos | SW_SM_8POS24V_TE |  |  |  |  |  |  |  |  |  |  |  |  |  |  |  |  |  |  |  |  |  |  |  |  | =Value |  |  |  | http://www.te.com/commerce/DocumentDelivery/DDEController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 | http://www.te.com/commerce/DocumentDelivery/DDEController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
TCA9534PWR | TSOP_PW16_L |  |  |  |  |  |  |  |  |  |  |  |  |  |  |  |  |  |  |  |  |  |  |  |  | TCA9534PWR |  |  |  | Datasheet | C:\Users\Public\Documents\Altium\AD16\Library\PDF\tca9534.pdf
TCA9543APWR | TSOP_PW14_L |  |  |  |  |  |  |  |  |  |  |  |  |  |  |  |  |  |  |  |  |  |  |  |  | TCA9543APWR |  |  |  | Datasheet | C:\Users\Public\Documents\Altium\AD16\Library\PDF\tca9543a.pdf
TEST PAD TH 51X36 | TP_PAD51D36 |  |  |  |  |  |  |  |  |  |  |  |  |  |  |  |  |  | Non BOM Item |  |  |  |  |  |  | Jumper
TPD8S009DSMR | DSM15 |  |  |  |  |  |  |  |  |  |  | Copyright (C) 2015 Accelerated Designs. All rights reserved |  |  |  |  |  |  |  |  |  |  |  |  |  | * |  |  |  |  |  |  |  |  |  |  |  |  |  |  |  |  |  |  |  |  |  |  |  | Copyright (C) 2015 Accelerated Designs. All rights reserved
TPS51200DRCT | DRC_S-PVSON-N10 |  |  |  |  |  |  |  |  |  |  |  |  |  |  |  |  |  |  |  |  |  |  |  |  | TPS51200DRCT |  |  |  | Datasheet | C:\Users\Public\Documents\Altium\AD16\Library\PDF\tps51200.pdf
TPS62173DSGT | WSON_08 |  |  |  |  |  |  |  |  |  |  |  |  |  |  |  |  |  |  |  |  |  |  |  |  | TPS62173DSGT |  |  |  | Datasheet | C:\Users\Public\Documents\Altium\AD16\Library\PDF\tps62173.pdf |  |  |  |  |  |  |  |  |  |  |  |  |  |  |  |  |  |  |  |  | 500mA
TXS0108EPWR | SOP65P640X120-20N |  |  |  |  |  |  |  |  |  |  |  |  |  |  |  |  |  | Integrated Circuits (ICs) |  | Bidirectional | 8 |  |  |  | TXS0108EPWR
Test Point | TP |  |  |  |  |  |  |  |  |  |  |  |  |  |  |  |  |  |  |  |  |  |  |  |  | TP
USB3320C-EZK | QFN50P500X500X100_HS-33N |  |  |  |  |  |  |  |  |  |  |  |  |  |  |  |  |  |  |  |  |  |  |  |  | USB3320C-EZK |  |  |  | Datasheet | C:\Users\Public\Documents\Altium\AD16\Library\PDF\00001792E.pdf
USB_MICROB_WURTH_629105136821 | USB_MICROB_WURTH_629105136821 |  |  |  |  |  |  |  |  |  |  |  |  |  |  |  |  |  |  |  |  |  |  |  |  | USB_MICROB_WURTH_629105136821 |  |  |  | Datasheet | C:\Users\Public\Documents\Altium\AD16\Library\PDF\629105136821.pdf
WL1835 | E-13.4X13.3-N100_0.75-TOP |  |  |  |  |  |  | Integrated, Chip |  |  |  |  |  |  |  |  |  |  | RF/IF and RFID |  |  |  |  |  |  | WL1835 |  |  |  |  |  |  |  |  |  |  |  |  |  |  |  |  |  |  |  |  |  |  |  |  |  |  |  |  |  | 85mA
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

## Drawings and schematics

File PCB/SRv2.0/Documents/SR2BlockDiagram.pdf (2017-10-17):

## POWER IN

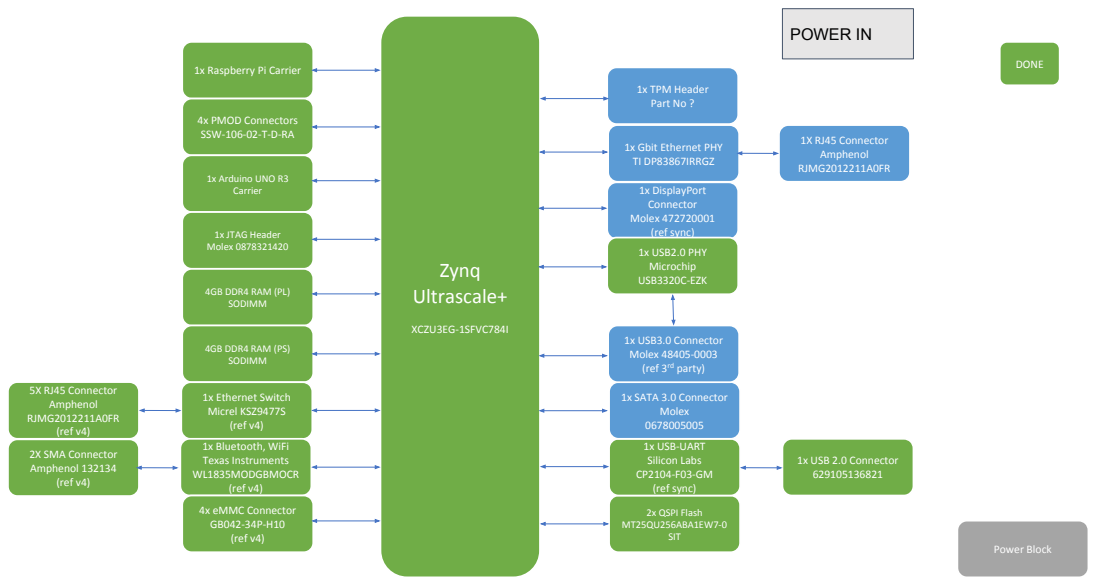
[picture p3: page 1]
Zynq Ultrascale+; XCZU3EG-1SFVC784I; 4x PMOD Connectors SSW-106-02-T-D-RA; 1x Arduino UNO R3 Carrier; 1x JTAG Header Molex 0878321420; 4GB DDR4 RAM (PL) SODIMM; 4GB DDR4 RAM (PS) SODIMM; 5X RJ45 Connector Amphenol RJMG2012211A0FR (ref v4); 1x Ethernet Switch Micrel KSZ9477S (ref v4); 1x Bluetooth, WiFi Texas Instruments WL1835MODGBMOCR (ref v4); 4x eMMC Connector GB042-34P-H10 (ref v4); 2x QSPI Flash MT25QU256ABA1EW7-0 SIT; 1x USB-UART Silicon Labs CP2104-F03-GM (ref sync)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

1x Raspberry Pi Carrier

1x Gbit Ethernet PHY
TI DP83867IRRGZ

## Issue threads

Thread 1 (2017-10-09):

Prepare Library of components for Subutai Router

bkukanov, 2017-10-09:
The Subutai Router 2.0 adds extra add-on features to SR 1.0, as well as it enhances the Ethernet Switch capability of SR 1.0 from Fast Ethernet to Gigabit Ethernet. We need to update the library and add component which are missing

metinburak, 2017-10-17:
Done except Ethernet PHY TI DP83867IRRGZ, displayport Molex 47272000, RJ45 RJMG2012211A0FR and SATA 3 0678005005.

bkukanov, 2017-10-24:
Displayport Molex 0472720001 has been added

bkukanov, 2017-10-24:
Ethernet PHY TI DP83867IRRGZ, displayport Molex 0472720001 and SATA 3 0678005005 has been added

bkukanov, 2017-12-21:
Done

Closed 2017-12-21.

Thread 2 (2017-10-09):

Block Design of Subutai Router

bkukanov, 2017-10-09:
The SR 2.0 adds extra add-on features to SR 1.0, as well as it enhances the Ethernet Switch capability of SR 1.0 from Fast Ethernet to Gigabit Ethernet.
The board adds a Raspberry extension connector connected to its Ultrascale FPGA PL I/Os, it also has an Arduino Uno R3 compatible extension connector which is also connected to PL FPGA I/Os. These 2 connectors, together with the 5 PMOD extension connectors gives user the ability to plug n play the COTS products to his SR 2.0.
- Our peripherals needed to check compatibility

metinburak, 2017-10-17:
@bkukanov  let's get this waterfall. The blok diagram will be in the PCB folder. Create the folder and push the block diagram pdf into there.

metinburak, 2017-10-17:
[sR2BlockDiagram.pdf](https://github.com/subutai-io/subutai-router/files/1392735/sR2BlockDiagram.pdf)

metinburak, 2017-10-17:
I have added @bkukanov .

Closed 2017-10-17.

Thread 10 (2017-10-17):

5 port Gigabit Ethernet Switch Schematic Capture

metinburak, 2017-10-17:
The 5 port Layer 2 controlled Micrel KSZ9477A Ethernet Switch and RJ45 connectors' schematic design will be handled in this issue.

metinburak, 2017-10-17:
Done in Sheet 13.

Closed 2017-10-17.

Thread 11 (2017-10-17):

Bluetooth 4.0 + Wifi b/g/n interface schematic capture

metinburak, 2017-10-17:
The WL1835 BT4.0 + Wifi 802.11 b/g/n schematic circuit will be handled in this issue.

metinburak, 2017-10-17:
Done in Sheet 14.

Closed 2017-10-17.

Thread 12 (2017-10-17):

eMMC interface schematic capture

metinburak, 2017-10-17:
4 x eMMC device interface circuit schematic will be handled in this issue.

metinburak, 2017-10-17:
Done in Sheet 12.

Closed 2017-10-17.

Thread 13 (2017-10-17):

TPM interface schematic capture

metinburak, 2017-10-17:
The TPM interface as header will be added to the design with this issue.

bkukanov, 2017-10-30:
Here little research about TPM header
https://superuser.com/questions/1216494/what-is-the-difference-between-various-tpm-modules
- ASUS TPM-M R2.0 (14 pin)  ->  TPM 2.0 compatible
- Asus TPM-L R2.0 (20 pin) ->  TPM 2.0 compatible
- Asus Trusted Platform Module TPM/FW3.19 (20 pins) -> TPM 1.2 compatible
- Gigabyte TPM Module GC-TPM2.0 (20 pins)

Asus header pinout http://forums.overclockers.com.au/threads/trusted-platform-module-asus-z170m-e-d3.1182000/

bkukanov, 2017-11-02:
I think it's better to use the header for 20 pin, because there is some compatibility with Asus TPM & Gigabit's TPM

bkukanov, 2017-11-02:
https://www.gigabyte.com/Motherboard/GC-TPM-rev-20#ov
http://download.gigabyte.ru/manual/mb_manual_ga-b250-hd3p_e.pdf
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

bkukanov, 2017-11-06:
done beside the eMMC header sheet

Closed 2017-11-06.

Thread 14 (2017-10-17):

PS Gigabit Ethernet PHY schematic capture

metinburak, 2017-10-17:
TI DP83867IRRGZ will be added to the schematic design with a RJ45 RJMG2012211A0FR connector.

bkukanov, 2017-10-20:
TI DP83867IRRGZ added to sheet ETH, now need to connect RJ45 RJMG2012211A0FR connector

bkukanov, 2017-10-23:
ETH-PHY sheet has been added with schematic design

Closed 2017-10-23.

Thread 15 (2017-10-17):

Display port schematic capture

metinburak, 2017-10-17:
472720001 connector will be added as a display port connector to the schematic design.

bkukanov, 2017-10-31:
Display port sheet added with schematic design

Closed 2017-10-31.

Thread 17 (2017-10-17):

USB 3.0 interface schematic capture

metinburak, 2017-10-17:
1x USB 3.0 interface will be added to the design with connector : Molex 48405-0003.

metinburak, 2017-10-17:
Done in Sheet 6.

Closed 2017-10-17.

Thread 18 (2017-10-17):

SATA 3.0 Interface schematic capture

metinburak, 2017-10-17:
1x SATA interface will be added to the schematic design with connector:
Molex 0678005005

metinburak, 2017-11-22:
@bkukanov  could u add this connector?

metinburak, 2017-11-22:
I will add the clock synthesizer btw, u don't mess up with clock synthesizer.

bkukanov, 2017-11-27:
SATA interface is added to sheet B505_clk

Closed 2017-11-27.

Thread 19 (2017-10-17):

USB-UART Interface Schematic Capture

metinburak, 2017-10-17:
1 x Silicon Labs
CP2104-F03-GM USB UART interface with connector 629105136821 will be added to the schematic design.

metinburak, 2017-10-17:
Done in Sheet 6.

Closed 2017-10-17.

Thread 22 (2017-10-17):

Generating the PL DDR4 controller's pinout in Vivado's latest (for Ultrascale)

metinburak, 2017-10-17:
The #8  needs this in order to connect the DDR4 module sch to Zynq. We will create a new project with Vivado based on Ultrascale and get the pinout.

metinburak, 2017-11-22:
@bkukanov we need this to route the PL SODIMM and also, any PL ios assigned so far in the pcb will be affected by this default pins generated by the PL ddr controller in vivado ultrazynq edition. What do u think?

bkukanov, 2017-11-23:
ok @metinburak  will look into it

bkukanov, 2017-11-27:
Here is the pin out of 64bit
[example_design_64bit.txt](https://github.com/subutai-io/subutai-router/files/1504894/example_design_64bit.txt)
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

bkukanov, 2017-11-27:
here is pin out for 72bit
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
[example_design_72bit.txt](https://github.com/subutai-io/subutai-router/files/1504899/example_design_72bit.txt)

Closed 2017-11-27.

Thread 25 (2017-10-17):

The Stackup Plan - Manufacturing Company Ping

metinburak, 2017-10-17:
The board dimensions and stack-up will be decided in this issue and the manufacturing capabilities will be discussed with the manufacturer company. The design rules should be updated after the interaction.

bkukanov, 2018-04-17:
Done

Closed 2018-04-17.

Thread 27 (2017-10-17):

PCB Cross-check

metinburak, 2017-10-17:
Review stage. All are welcome.

bkukanov, 2018-03-03:
@metinburak mounting holes are absent.
Does it better to put SATA power and Fan power socket for zynq cooler?

bkukanov, 2018-04-17:
on production stage

Closed 2018-04-17.

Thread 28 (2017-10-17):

Generation and sending the Fabrication Files

metinburak, 2017-10-17:
The Gerber and NC Drill will be sent to PCB manufacturer, while the BOM will also be generated.

bkukanov, 2018-04-17:
On production stage

Closed 2018-04-17.

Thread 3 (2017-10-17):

Power Requirement Analysis

metinburak, 2017-10-17:
The overall power requirement of the router will be analyzed.

metinburak, 2017-10-17:
ongoing in the Power Requirement Document in the PCB folder. @bkukanov  FYI.

metinburak, 2017-10-26:
Done with the power requirement analysis.

metinburak, 2017-10-26:
We're going with the LMZ23610 (main), EN5367QI,TPS51200DRCT and so on with the rail voltage redulators.

Closed 2017-10-26.

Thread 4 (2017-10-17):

Raspberry Pi Expansion Schematic Capture

metinburak, 2017-10-17:
The Raspberry Pi Expansion Circuit will be designed.

metinburak, 2017-10-17:
Done, but the Sheet id will be written here.

metinburak, 2017-11-22:
I can not understand where it is, i have added it before, @bkukanov  please could u add it?

bkukanov, 2017-11-28:
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
Rasperry pi header was added

bkukanov, 2017-12-04:
We need to modify the CAD file

bkukanov, 2017-12-05:
It was added to design PMOD_ARD_RASP sheet

Closed 2017-12-05.

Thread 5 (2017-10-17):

Arduino Uno r3 Expansion Schematic Capture

metinburak, 2017-10-17:
Arduino Uno r3 Expansion circuit schematic will be designed.

metinburak, 2017-10-17:
Done in Sheet 7.

bkukanov, 2017-12-04:
we need to add the Analog/Digital inputs

Closed 2017-12-05.

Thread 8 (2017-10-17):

PL side DDR4 SODIMM schematic capture

metinburak, 2017-10-17:
The PL side DDR4 circuit schematic design will be handled in this issue.

metinburak, 2017-10-17:
#22 will get us the pinout with a Zynq Ultrascale+ project witha aPL DDR4 controller.

metinburak, 2017-10-17:
PL DDR SODIMM module is in Sheet 15.

bkukanov, 2017-12-13:
PL DDR SODIMM schematic PL_DDR4_SODIMM sheet

Closed 2017-12-13.

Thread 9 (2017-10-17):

PS side DDR4 SODIMM schematic capture

metinburak, 2017-10-17:
The PS side 4 GB DDR4 SODIMM schematic design will be handled in this issue.

metinburak, 2017-10-17:
The schematic capture of DDR4 module is done, but for the connection of module to Zynq, a design should be generated in the Vivado's latest version to get the pinout correctly. Waiting for #22.

metinburak, 2017-10-17:
Done in Sheet 8 and Sheet 10.

Closed 2017-10-17.

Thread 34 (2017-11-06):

The Subutai Router v2.0 schematic design review

bkukanov, 2017-11-06:
The Subutai Router v2.0 schematic design will be analysed for compatibly of peripherals and checked the design

bkukanov, 2017-11-20:
we need to add MAC Address, SATA interface & clock synthesizer

bkukanov, 2017-11-23:
JTAG header not connected

bkukanov, 2017-12-11:
The MIO parts have to be connected fully and re-analyzed.
Zynq PL side has to be connected

bkukanov, 2017-12-12:
While compiling project there are some duplicate net errors

bkukanov, 2017-12-13:
There are PL DDR4 duplicate net errors

bkukanov, 2017-12-26:
@metinburak PMOD_ARD_RASP hasn't connected to the Zynq IO

bkukanov, 2018-01-09:
Mechanical mounting holes are required to added

bkukanov, 2018-04-17:
done

Closed 2018-04-17.

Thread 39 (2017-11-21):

PS GTR clock synthesizer

bkukanov, 2017-11-21:
We need to add GTR clock synthesizer sheet

bkukanov, 2017-11-23:
@metinburak there is missing footprint of clock generator and the design not finished

bkukanov, 2017-12-13:
The schematic on PS_GTR sheet

Closed 2017-12-13.

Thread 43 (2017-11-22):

USB 5V Vdd from Power Regulator

metinburak, 2017-11-22:
In Power regulator need to add 5V VDD for USB interface

bkukanov, 2017-12-14:
The schematic has been added in power sheet

bkukanov, 2017-12-21:
Done

Closed 2017-12-21.

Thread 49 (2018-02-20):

PCB design adding a text describing the expansions

bkukanov, 2018-02-20:
We need to add the text and information of company:
- Logo of company
- Logo of partners
- Website
- Version
- Date
- Rasp, Arduino
- Power in + -
- Ps/pl DDR texts
- Switch/ main eth text
- give pmods numbers: 1,2 or a,b
- Numbers to emmcs
- DVI, SATA, USB3, JTAG texts

bkukanov, 2018-02-21:
Top overlay designators placement corrected

bkukanov, 2018-02-22:
Bottom overlay has been corrected

bkukanov, 2018-02-24:
Done

Closed 2018-02-24.

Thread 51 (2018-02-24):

Mounting holes are missed

bkukanov, 2018-02-24:
We need to add mounting holes to board

bkukanov, 2018-03-22:
Done

Closed 2018-03-22.

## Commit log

2017-10-17 Subutai Router 2.0 design files- schmatic capture and PCB and sch libraries
    [PCB1.PcbDoc, Sheet1.SchDoc, Sheet10.SchDoc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]
2017-10-17 sch and pcb libraries are added
    [Ultrascale_SchLib.SchLib]
2017-10-17 Power Requirement Analysis Preliminary, Document has been added.
    [SR2_Power_Consumption.xlsx]
2017-10-18 #1 Library preparation
    [ETH-PHY.SchDoc, PCB.PcbDoc, SATA_GiGE.SchDoc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]
2017-10-23 Gigabit Ethernet sheet added #14
    [ETH-PHY.SchDoc, SATA_GiGE.SchDoc, Schlib.SchLib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]
2017-10-23 Project folder organization & sheet renaming
    [DDR4_PWR.SchDoc, ETH-PHY.SchDoc, PCB.PcbDoc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]
2017-10-24 sheets name renamed #21
    [Arduino_PMOD.SchDoc, JTAG.SchDoc, QSPI_Flash.SchDoc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]
2017-10-24 Display port library updated #15
    [DisplayPort.SchDoc, ETH-PHY.SchDoc, USB3.0_UART.SchDoc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]
2017-10-24 #1 Library updated 0678005005, DP83867IRRGZ and 0472720001 has been added
    [Ultrascale_SchLib.SchLib]
2017-10-26 Issue #3 has been resolved.
    [DDR4_Power_Calc.xlsm, DDR4_Power_Calc.xlsm.xlsx, SR2_Power_Consumption.xlsx]
2017-10-30 #15 Display port schematic design
    [DisplayPort.SchDoc, Ultrascale_SchLib.SchLib]
2017-10-31 #15 Display port schematic updated
    [DisplayPort.SchDoc, ETH-PHY.SchDoc, Ultrascale.PrjPcb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]
2017-11-03 #13 TPM schematic design
    [DisplayPort.SchDoc, ETH-PHY.SchDoc, QSPI_Flash.SchDoc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]
2017-11-04 #13 TPM footprint updated
    [Ultrascale.PrjPcb, Ultrascale_SchLib.SchLib, eMMC.SchDoc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]
2017-11-10 I have committed my sources, we will take care of merging the libraries
    [Arduino_PMOD.SchDoc, DDR4_PWR.SchDoc, DisplayPort.SchDoc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]
2017-11-13 #34 2 projects schematic design merged
    [B24.SchDoc, B504_DDR4.SchDoc, DisplayPort.SchDoc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]
2017-11-13 #34 project library added
    [DisplayPort.SchDoc, Ultrascale.PrjPcb, Ultrascale_SchLib.SchLib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]
2017-11-13 sch and pcb libraries added.
2017-11-14 #34 Library merged
    [Ultrascale_SchLib.SchLib]
2017-11-15 Library updated by adding the Manufacturer parameters #35
    [B24.SchDoc, B504_DDR4.SchDoc, DisplayPort.SchDoc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]
2017-11-16 components are updated #35
    [DisplayPort.SchDoc, ETH-PHY.SchDoc, Ultrascale_SchLib.SchLib]
2017-11-16 Library updated #35
    [ETH-PHY.SchDoc, Power1.SchDoc, Power2.SchDoc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]
2017-11-22 PS GTR clock synthesizer added #39
    [B24.SchDoc, B505_Clk_syn.SchDoc, Ultrascale.PrjPcb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]
2017-11-23 PS GTR clock generator updated
    [B505_Clk_syn.SchDoc, Ultrascale.PrjPcb, Ultrascale_SchLib.SchLib]
2017-11-27 SATA interface added #18
    [B505_Clk_syn.SchDoc, Ultrascale_SchLib.SchLib]
2017-11-29 Raspberry pi symbol and footprint added #4
    [PMOD_ARD.SchDoc, Ultrascale_SchLib.SchLib]
2017-12-04 PL DDR, Clock Sync and others that will be specified in the Github Issues have been added
    [DDR4_SODIMM_PWR.SchDoc, DisplayPort.SchDoc, ETH-PHY.SchDoc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]
2017-12-04 Arduiono schematic updated #5
    [B505_Clk_syn.SchDoc, PMOD_ARD.SchDoc, Ultrascale_SchLib.SchLib]
2017-12-05 Projects are merged
    [PMOD_ARD_RASP.SchDoc, Ultrascale.PrjPcb]
2017-12-05 Arduino connection updated #5
    [PMOD_ARD_RASP.SchDoc]
2017-12-21 Burak's review the schematic design #38
    [DisplayPort.SchDoc, ETH-PHY.SchDoc, Eth_Switch.SchDoc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]
2017-12-21 Burak's PCB layout preparation #23
    [DDR4_SODIMM_PWR.SchDoc, DisplayPort.SchDoc, ETH-PHY.SchDoc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]
